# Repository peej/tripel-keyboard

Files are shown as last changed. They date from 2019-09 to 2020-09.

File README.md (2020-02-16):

# Tripel - Ortholinear 60% keyboard PCB

Tripel is a 15 column ortholinear keyboard PCB.

The goal of this project is to build an all throughhole component, pro-micro powered ortholinear PCB that fits in a standard 60% tray mount case but built from sub-100x100mm PCB boards.

Inspired by the modular PCB projects of [40Percent.club](http://www.40percent.club/) like the [Nori](http://www.40percent.club/2018/10/nori.html).

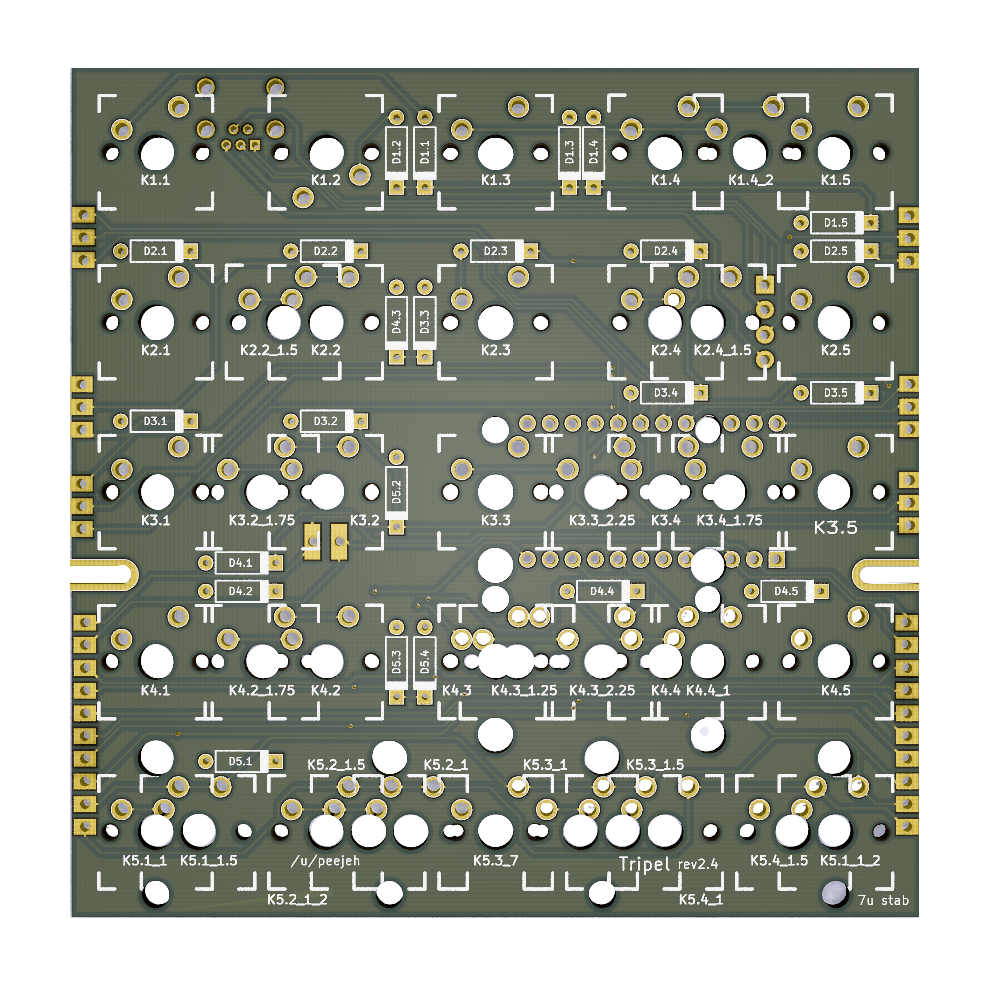
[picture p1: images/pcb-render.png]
PCB render


* Designed to be easy to build with minimal soldering experience.
* Built from 3 of the same PCB.
* 7u spacebar bottom row.

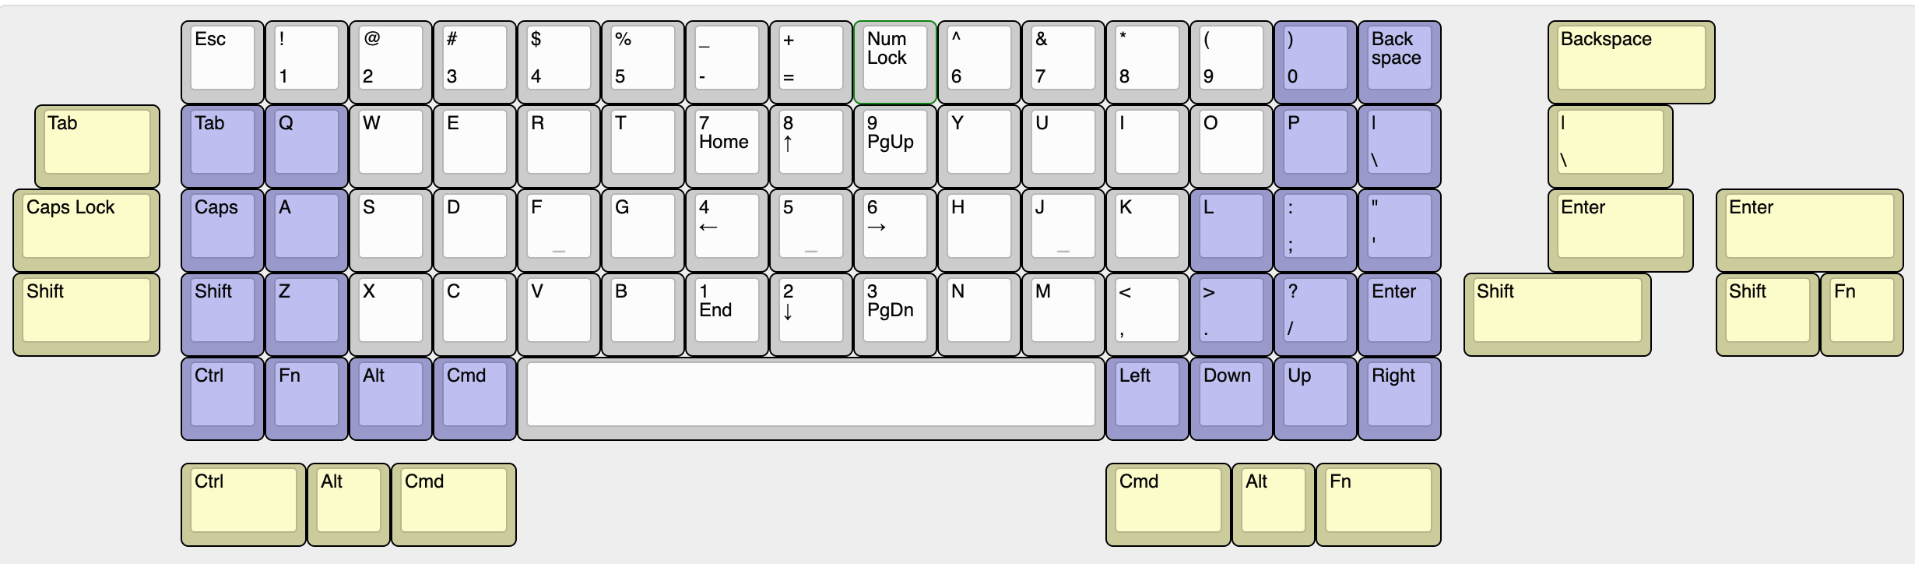
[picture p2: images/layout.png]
Layout options

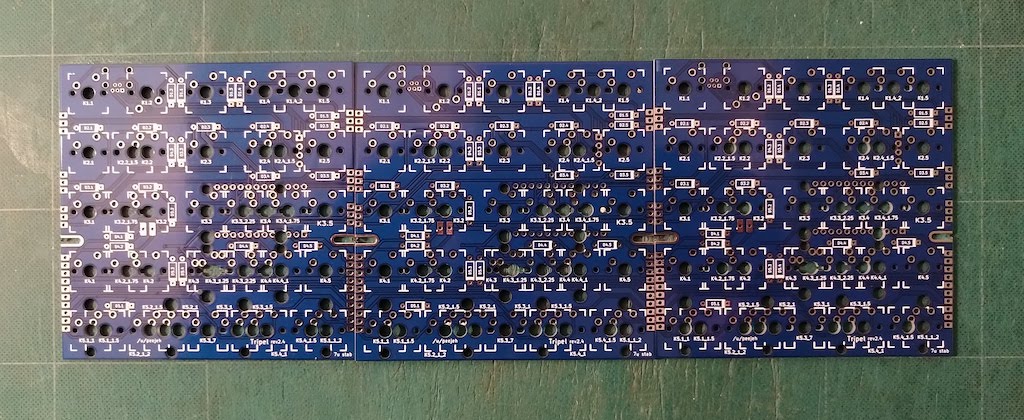
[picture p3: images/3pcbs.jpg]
PCBs layed out

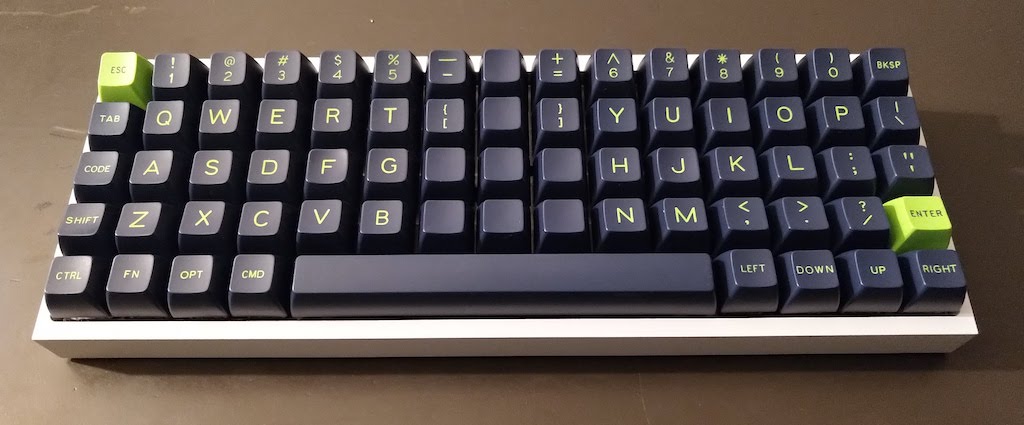
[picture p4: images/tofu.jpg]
Built keyboard


# Bill of Materials (BOM)

* 3 PCBs.
* A suitable 60% ortholinear keyboard plate (eg. [XD75 plate](https://kprepublic.com/collections/xd75/products/stainless-steel-plate-for-xd75re-60-custom-keyboard-mechanical-keyboard-plate-support-xd75re)).
* 65 MX compatible switches.
* 65 1n4148 diodes.
* Pro Micro controller (or compatible alternative).
* 7u PCB mount stabilizer.
* Through-hole USB mini or micro connector.
* USB cable for Pro Micro.

# Ordering PCBs

PCBs can be manufactuered by a variety of online PCB fabricators. You can use [PCBShopper](https://pcbshopper.com/) to search for the best price. Many manufacturers have special rates for prototype boards under 100x100mm in size.

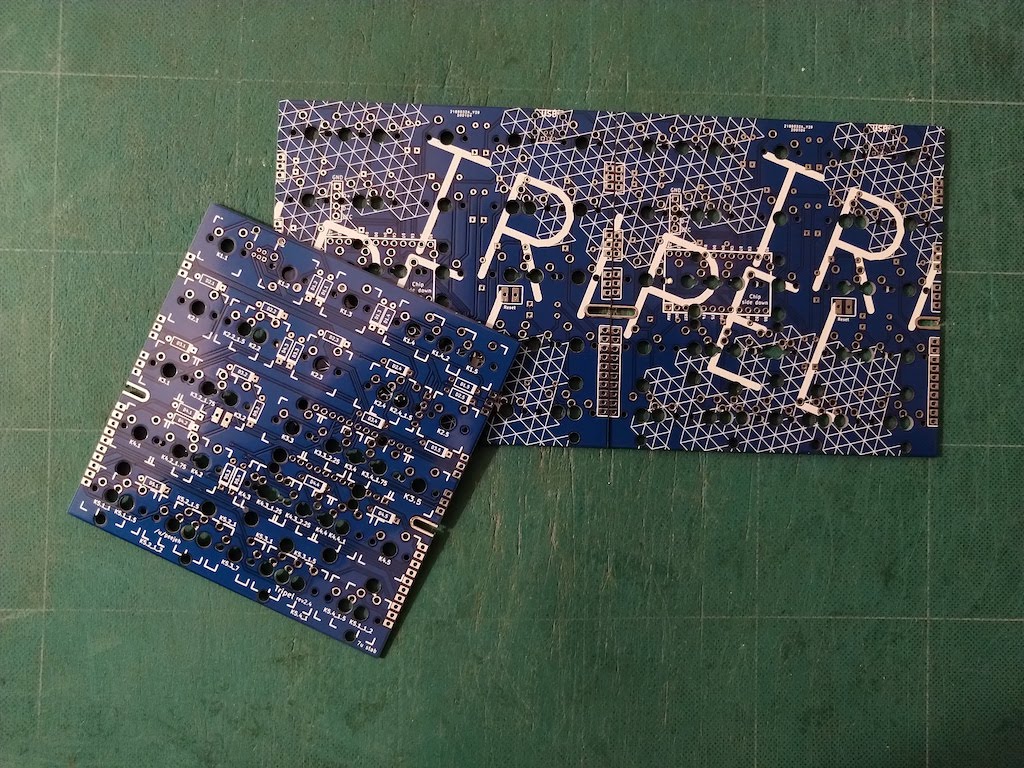
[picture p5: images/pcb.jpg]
PCBs


The zip file in the gerber directory contains the gerber files your fabricator will need to make the PCB [tripel.zip](https://github.com/peej/tripel-keyboard/blob/master/gerber/tripel.zip) PCB.

When uploading the gerber zip files, use the default PCB settings.

# Construction

* You will need 3 PCBs.
* Solder the diodes onto each PCB.
  * You can place them on either side, but the drawing on the soldermask is on the front of the PCB.
  * The diodes under the Pro Micro must go on the front side of the PCB.
  * The end of the diode with black band goes in the square hole.
* Solder on the Pro Micro headers onto the underside of one PCB.
  * Do not solder on the Pro Micro yet.
  * You can place the Pro Micro on any of the 3 PCBs, pick the placement that works best for your case.
  * To get keep the headers straight while soldering, place the Pro Micro over the headers to hold them in place.
  * If you want to use a socket for your Pro Micro, solder on a socket instead.
* Solder on the USB connector to the underside of the left PCB.
* Insert the switches into the plate.
  * If using a XD75 ortholinear plate, you will need to modify it if you are using an incompatible layout.
* Join the PCBs together by solder the solder bridges between the PCBs.
  * Solder all pad bridges between the 3 PCBs.
  * Use small bent pieces of trimmed diode wire to bridge the solder bridges instead of just using solder.
* Put the 7u stabilizer together and fit it into the left and right PCBs.
  * If you are using the standard modifier keycap sizes, you will also want to add 2u stabs for those keys.
  * If you forget the stabilizer you will need to unsolder all of the switches so as to fit it.
  * Don't forget to trim and lube your stabilizer before fitting if you want to.
* Place the PCBs onto the switches:
  * Insert all the switches and ensure that the pins of each switch are correctly coming through the board and are not bent under the PCB.
* Solder all the switch pins.
  * Some switches might foul on your case mounting posts stopping the PCB from sitting flush, before soldering, trim the switch pins which would foul so they are flush with the PCB.
  * The switch next to the Pro Micro might need to have it's pins trimmed so that your USB cable can plug in and sit as flush as possible to the PCB.
* Solder on the Pro Micro:
  * Ensure that you have it the correct way around, the chip side should be face down towards the PCB with the USB port to the right.
  * You might want to plug in your USB cable while soldering so that the Pro Micro is mounted far enough from the PCB for the cable to plug in successfully.
  * Use electrical tape underneath the Pro Micro if you think shorting against the switch pins could be an issue.
* Cut your USB cable to length and solder the wires to the pads for the USB connector.
 * Wire colours may vary, but usually: Red = VCC; black = GND; white = D-; green = D+

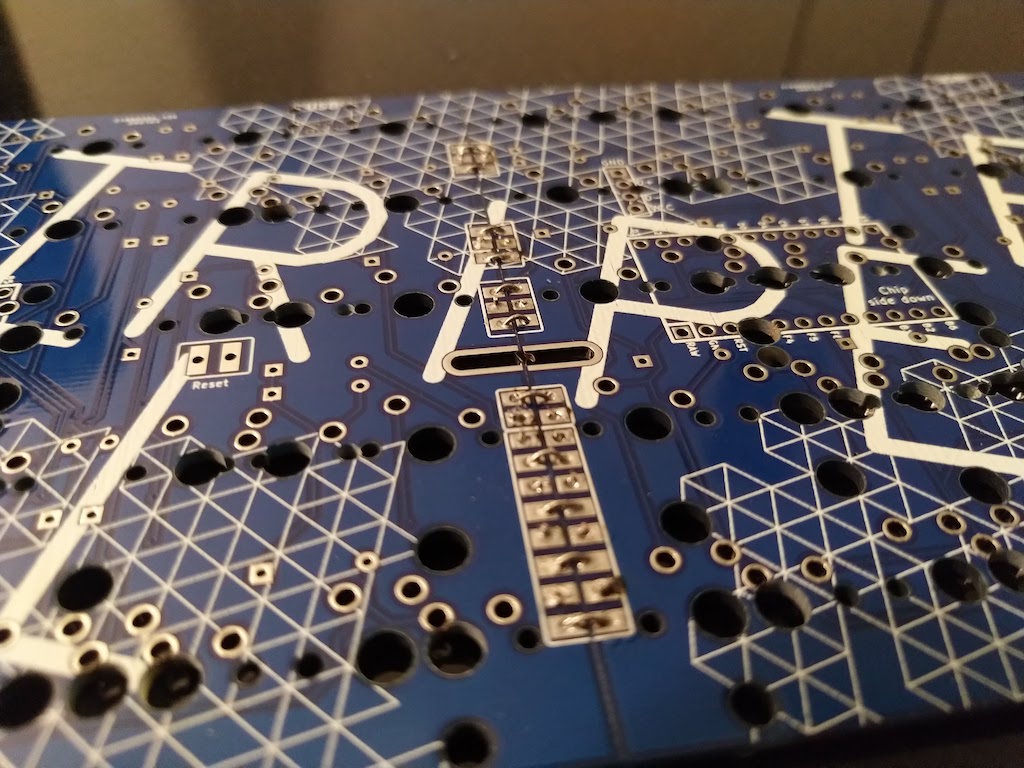
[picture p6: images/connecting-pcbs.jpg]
Connecting the PCBs together


# Firmware

Build and flash the Pro Micro with QMK firmware, see the [QMK documentation](http://qmk.fm/) on how to do this.

The required pinout for the firmware is shown in [this KLE layout](http://www.keyboard-layout-editor.com/#/gists/6fe5d6cc536d3c9c028186f25ce0c42f):

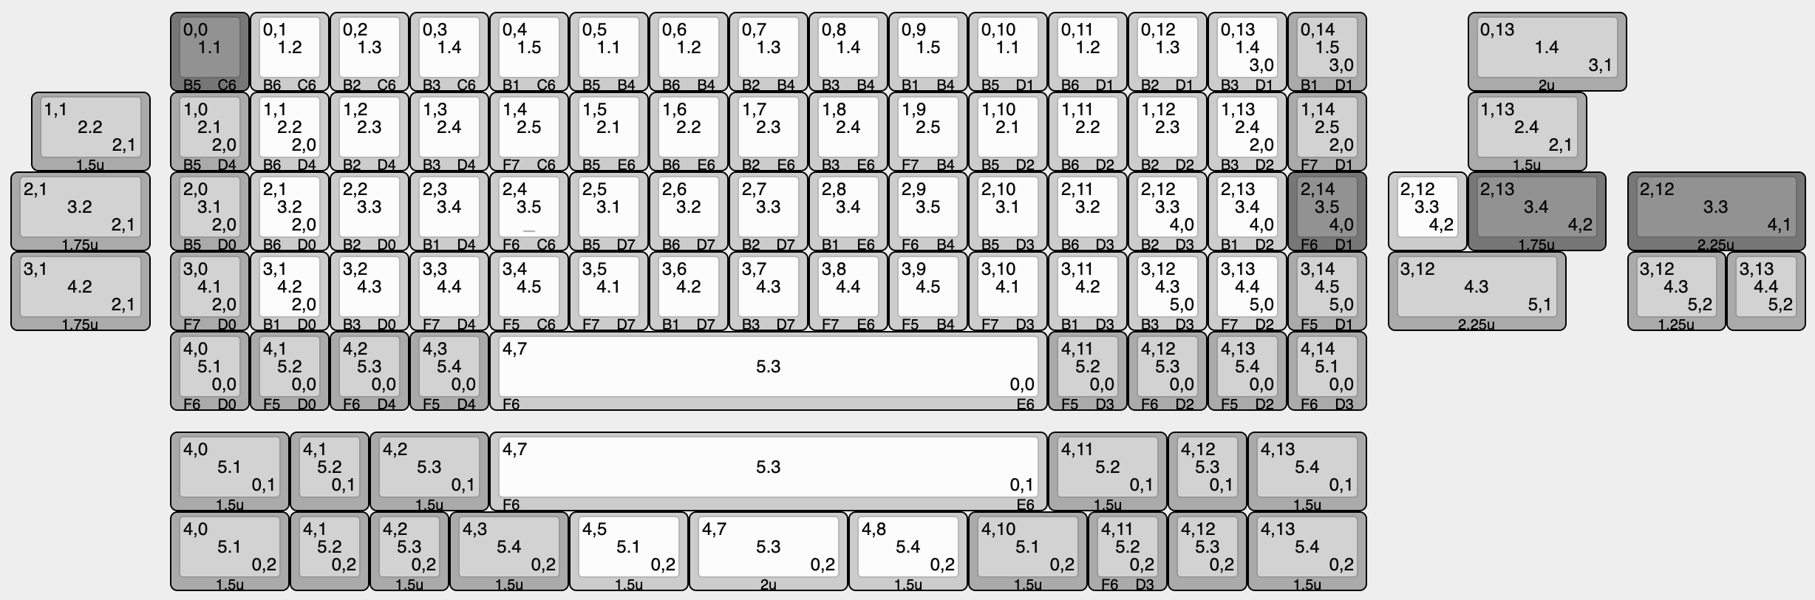
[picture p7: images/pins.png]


A preconfigured firmware is not yet available in the QMK repo but can be [found here in my fork](https://github.com/peej/qmk_firmware/tree/master/keyboards/tripel).

# Differences to the XD75

The main difference to the XD75 is the alternative layout options.

* Supports PCB mount stabilizers for a 7u (or 2u) "spacebar"
* Supports PCB mount stabilizers for non-1u layout, 2u "backspace", 2.75u "enter" and "right shift" keys.
* The Tripel does not support the full-grid layout of the XD75 as there are not enough pins on the Pro Micro

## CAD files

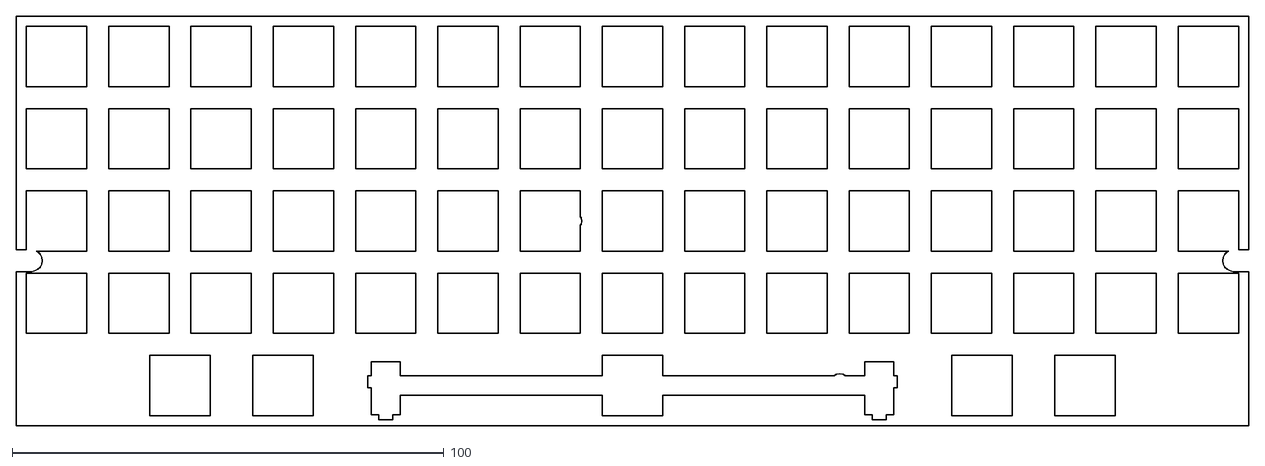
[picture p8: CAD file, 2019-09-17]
tripel.dxf
285.4 x 94.9

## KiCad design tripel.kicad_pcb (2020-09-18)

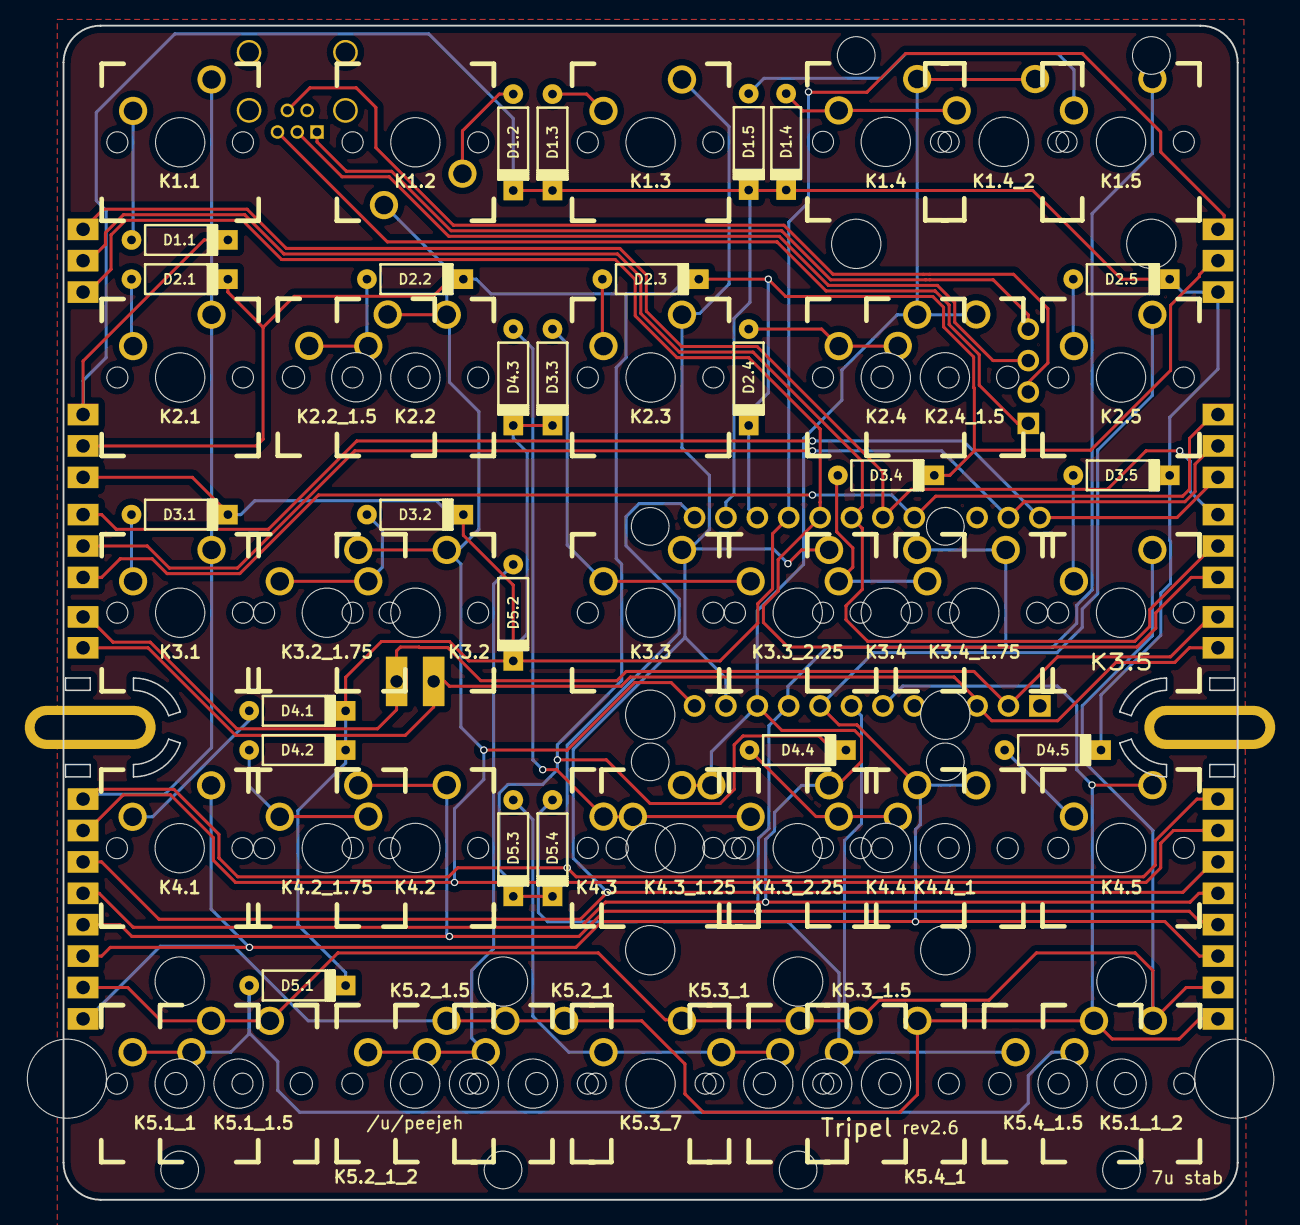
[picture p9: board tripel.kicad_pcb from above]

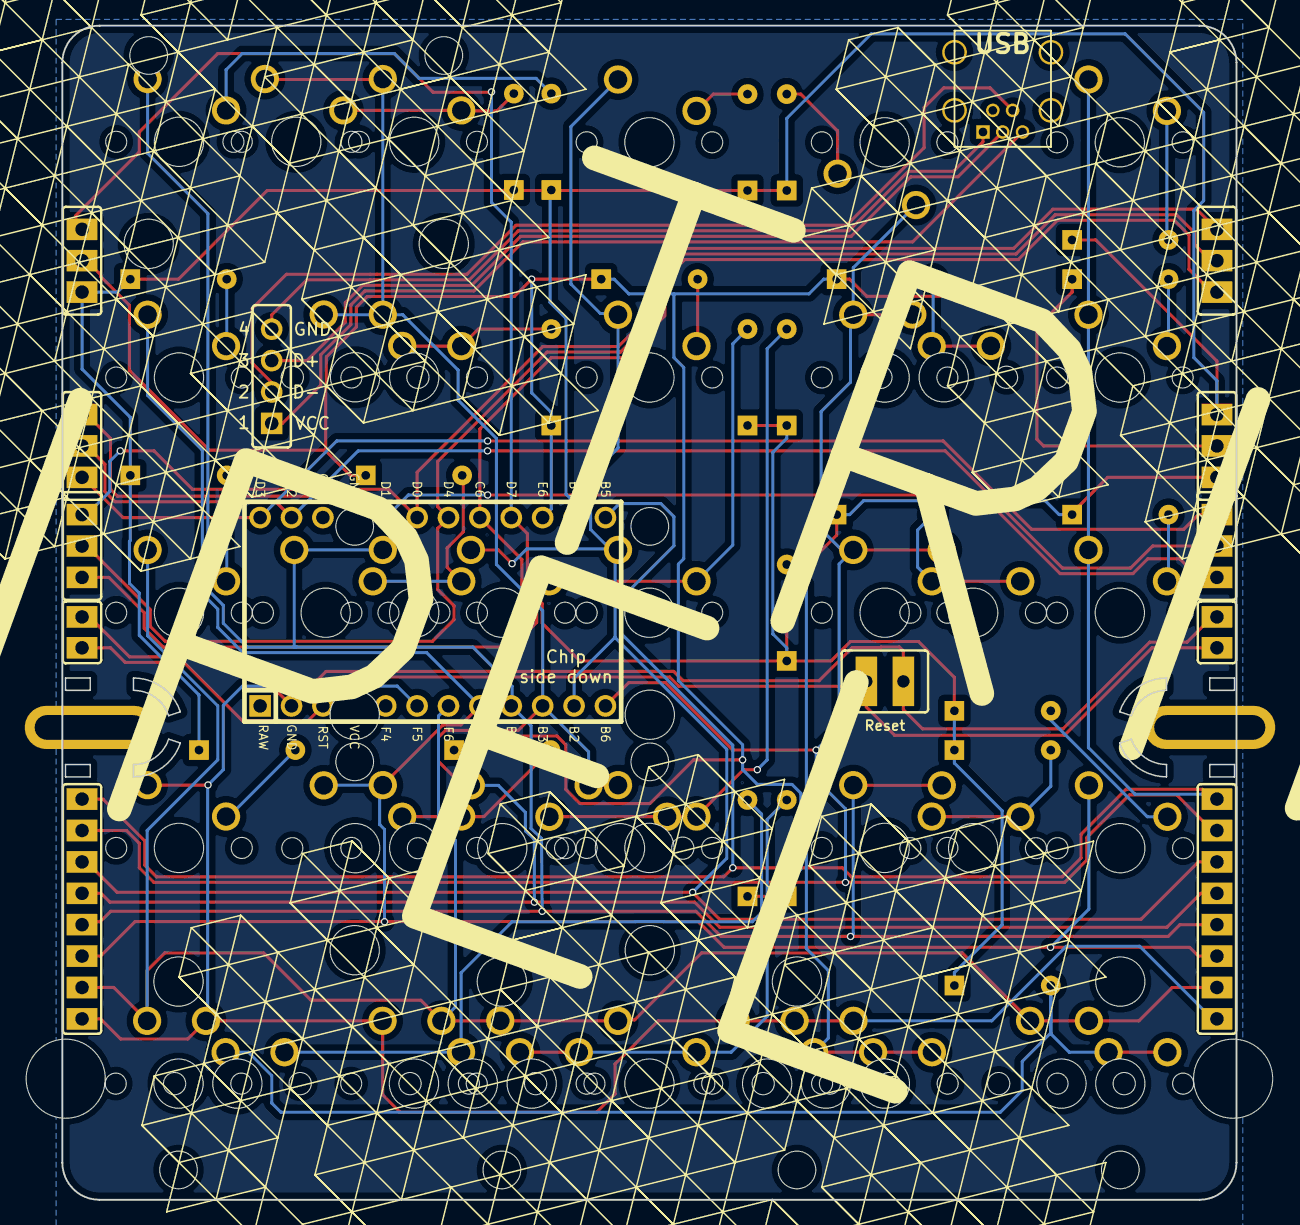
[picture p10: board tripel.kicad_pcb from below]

Board: 2 copper layers, 95.0 x 95.0 mm, 79 parts (14 on the bottom side), 47 nets.

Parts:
D1.1, D1.2, D1.3, D1.4, D1.5, D2.1, D2.2, D2.3, D2.4, D2.5, D3.1, D3.2, D3.3, D3.4, D3.5, D4.1, D4.2, D4.3, D4.4, D4.5, D5.1, D5.2, D5.3, D5.4: D; DIODE
J1: Left Columns; CONNECTOR_8
J2, J5: Left Rows; CONNECTOR_3
J3, J8: Right Rows; CONNECTOR_3
J4: Right Columns; CONNECTOR_8
J6: USB_mini_micro_B; USB_Mini-B
J7: Conn_01x04; CONNECTOR_4
J9: Reset; RESET
J10: Right Reset; CONNECTOR_2
J11: Left Reset; CONNECTOR_2
J12, J13: Far Left Rows; CONNECTOR_3
K1.1, K1.2, K1.3, K1.4, K1.5, K2.1, K2.2, K2.3, K2.4, K2.5, K3.1, K3.2, K3.3, K3.4, K3.5, K4.1, K4.2, K4.3, K4.4, K4.4_1, K4.5, K5.1_1, K5.1_1_2, K5.2_1, K5.2_1_2, K5.3_1, K5.4_1: KEYSW; MX
K1.4_2, K5.3_7: KEYSW; MX_PCB_200H
K2.2_1.5, K2.4_1.5, K5.1_1.5, K5.2_1.5, K5.3_1.5, K5.4_1.5: KEYSW; MX_PCB_150H
K3.2_1.75, K3.4_1.75, K4.2_1.75: KEYSW; MX_PCB_175H
K3.3_2.25, K4.3_2.25: KEYSW; MX_PCB_225H
K4.3_1.25: KEYSW; MX_PCB_125H
U1: ProMicro_ChipSideDown; Pro_Micro_ChipSideDown

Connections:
unnamed: D1.1.1, D1.2.1, D1.3.1, D1.4.1, D1.5.1, D2.5.1, D3.5.1, D4.5.1, J5.1, J8.3, U1.23
unnamed: D1.1.2, K1.1.2
unnamed: D1.2.2, K1.2.2
unnamed: D1.3.2, K1.3.2
unnamed: D1.4.2, K1.4.2, K1.4_2.2
unnamed: D1.5.2, K1.5.2
unnamed: D2.1.1, D2.2.1, D2.3.1, D2.4.1, D3.4.1, D4.4.1, D5.3.1, D5.4.1, J5.2, J8.2, U1.22
unnamed: D2.1.2, K2.1.2
unnamed: D2.2.2, K2.2.2, K2.2_1.5.2
unnamed: D2.3.2, K2.3.2
unnamed: D2.4.2, K2.4.2, K2.4_1.5.2
unnamed: D2.5.2, K2.5.2
unnamed: D3.1.1, D3.2.1, D3.3.1, D4.1.1, D4.2.1, D4.3.1, D5.1.1, D5.2.1, J5.3, J8.1, U1.21
unnamed: D3.1.2, K3.1.2
unnamed: D3.2.2, K3.2.2, K3.2_1.75.2
unnamed: D3.3.2, K3.3.2, K3.3_2.25.2
unnamed: D3.4.2, K3.4.2, K3.4_1.75.2
unnamed: D3.5.2, K3.5.2
unnamed: D4.1.2, K4.1.2
unnamed: D4.2.2, K4.2.2, K4.2_1.75.2
unnamed: D4.3.2, K4.3.2, K4.3_1.25.2, K4.3_2.25.2
unnamed: D4.4.2, K4.4.2, K4.4_1.2
unnamed: D4.5.2, K4.5.2
unnamed: D5.1.2, K5.1_1.2, K5.1_1.5.2, K5.1_1_2.2
unnamed: D5.2.2, K5.2_1.2, K5.2_1.5.2, K5.2_1_2.2
unnamed: D5.3.2, K5.3_1.2, K5.3_1.5.2, K5.3_7.2
unnamed: D5.4.2, K5.4_1.2, K5.4_1.5.2
unnamed: J1.1, J4.1, K4.5.1, K5.2_1.1, K5.2_1.5.1, K5.2_1_2.1, K5.4_1.1, K5.4_1.5.1, U1.6
unnamed: J1.2, J4.2, K3.5.1, K5.1_1.1, K5.1_1.5.1, K5.1_1_2.1, K5.3_1.1, K5.3_1.5.1, K5.3_7.1, U1.7
unnamed: J1.3, J4.3, K2.5.1, K4.1.1, K4.4.1, K4.4_1.1, U1.8
unnamed: J1.4, J4.4, K1.5.1, K3.4.1, K3.4_1.75.1, K4.2.1, K4.2_1.75.1, U1.9
unnamed: J1.5, J4.5, K1.4.1, K1.4_2.1, K2.4.1, K2.4_1.5.1, K4.3.1, K4.3_1.25.1, K4.3_2.25.1, U1.10
unnamed: J1.6, J4.6, K1.3.1, K2.3.1, K3.3.1, K3.3_2.25.1, U1.11
unnamed: J1.7, J4.7, K1.2.1, K2.2.1, K2.2_1.5.1, K3.2.1, K3.2_1.75.1, U1.12
unnamed: J1.8, J4.8, K1.1.1, K2.1.1, K3.1.1, U1.24
unnamed: J6.1, J7.1
unnamed: J6.2, J7.2
unnamed: J6.3, J7.3
unnamed: J6.5, J7.4
unnamed: J9.1, J10.1, J11.1, U1.2
unnamed: J9.2, J10.2, J11.2, U1.3
unnamed: J3.1, J12.1, U1.20
unnamed: J3.2, J12.2, U1.19
unnamed: J3.3, J12.3, U1.18
unnamed: J2.1, J13.1, U1.17
unnamed: J2.2, J13.2, U1.14
unnamed: J2.3, J13.3, U1.13

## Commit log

2019-10-01 Add prototype PCB image
2019-10-10 Add split spacebar bottom row
    [tripel-B_Cu.gbl, tripel-B_Mask.gbs, tripel-B_Paste.gbp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]
2019-10-25 Increase size of mounting hole to ease case installation
    [tripel-B_Cu.gbl, tripel-B_Mask.gbs, tripel-B_Paste.gbp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]
2019-10-29 Flip stabilizer mounting holes
    [tripel-B_Cu.gbl, tripel-B_Mask.gbs, tripel-B_Paste.gbp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]
2019-11-01 Fix right side PCB connection
    [tripel-B_Cu.gbl, tripel-B_Mask.gbs, tripel-B_Paste.gbp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]
2019-11-02 Adjust connector pad positions
    [tripel.kicad_pcb]
2019-11-02 Switch to single sided design
    [tripel-B_Cu.gbl, tripel-B_Mask.gbs, tripel-B_Paste.gbp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]
2019-11-03 Add some backside silkscreen patterns
    [tripel-B_Cu.gbl, tripel-B_Mask.gbs, tripel-B_Paste.gbp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]
2019-11-16 Add 4x1u bottom row option
    [tripel-B_Cu.gbl, tripel-B_Mask.gbs, tripel-B_Paste.gbp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]
2019-11-16 Fix Pro Micro silkmask
    [tripel-B_Cu.gbl, tripel-B_Mask.gbs, tripel-B_Paste.gbp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]
2019-11-16 Breakout reset pads
    [tripel-B_Cu.gbl, tripel-B_Mask.gbs, tripel-B_Paste.gbp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]
2019-11-18 Update gerbers zip
2019-11-18 Update PCB images
2019-11-23 Rename diodes to match the name of their corrisponding switch
    [tripel-B_Cu.gbl, tripel-B_Mask.gbs, tripel-B_Paste.gbp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]
2019-12-10 Move USB pads to more convenient location
    [tripel-B_Cu.gbl, tripel-B_Mask.gbs, tripel-B_Paste.gbp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]
2019-12-14 Flip USB footprint to correct side of board
    [tripel-B_Cu.gbl, tripel-B_Mask.gbs, tripel-B_Paste.gbp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]
2019-12-28 Add switch footprints for alternative mod sizes
    This introduces a number of changes so as toallow standard sized mod keys to be used. This required moving of a number of components so as to make space for 2u key stabilizers.
    Changes include:
    * Move Pro-Micro to the right to avoid stabilizer mounting holes
    * Add extra connections between boards to allow Pro-Micro to be placed on any of the PCBs
    * Remove USB pertrusion and flip orientation of K1.2 to be north facing
    * Add extra connections so that reset pads can be accessed via hole in case even in Pro-Micro is on a different PCB
    [tripel-B_Cu.gbl, tripel-B_Mask.gbs, tripel-B_Paste.gbp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]
2019-12-28 Update PCB render
2020-01-03 Add split right shift and 1.75u enter options
    [tripel-B_Cu.gbl, tripel-B_Mask.gbs, tripel-B_Paste.gbp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]
2020-02-02 Add stab holes for 2u backspace
    [tripel-B_Cu.gbl, tripel-B_Mask.gbs, tripel-B_Paste.gbp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]
2020-09-13 Move inter-PCB contacts away from PCB edge to help prevent shorts
    [tripel-B_Cu.gbl, tripel-B_Mask.gbs, tripel-B_Paste.gbp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]
2020-09-16 Add removable mounting holes
    [tripel-B_Cu.gbl, tripel-B_Mask.gbs, tripel-B_Paste.gbp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]
2020-09-18 Change USB header pin spacing to standard size
    [tripel-B_Cu.gbl, tripel-B_Mask.gbs, tripel-B_Paste.gbp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]
